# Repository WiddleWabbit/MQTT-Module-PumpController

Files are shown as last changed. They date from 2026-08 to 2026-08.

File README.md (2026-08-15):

# MQTT Module Pump Controller

*This Module is in testing and not fully tested.*

Module for the [MQTT Modular Controller Board](https://github.com/WiddleWabbit/MQTT-ModularControllerBoard). Controls and powers a single small 12 V pump.

## Features

- ATtiny1614 microcontroller
- I²C communication with motherboard (SDA/SCL)
- N-channel MOSFET + LM5060 high-side driver for pump control
- Overvoltage, undervoltage, and overcurrent protection
- Flyback diode, TVS, and filtering on pump output
- Green LED (pump running) and yellow LED (fault)
- 3-pin UPDI programming interface
- Adjustable passives for different pumps
- Maximum continuous pump current: 5 A

## Architecture

### Core Components

- **Microcontroller**: ATtiny1614
- **Pump Driver**: N-channel MOSFET paired with LM5060
- **Maximum Pump Current**: 5 A continuous
- **Programming**: 3-pin UPDI on PA0 (default fuse configuration: RSTPINCFG in FUSE.SYSCFG0 = 0x1)

### Protection (LM5060)

- **Overvoltage**: Triggers at 15.6 V (rising), releases at 13.7 V (falling)
- **Undervoltage**: Triggers at 9.3 V (falling), releases at 10.5 V (rising)
- **Overcurrent**: Fault threshold ~5.69 A
- **Timing**:
  - Startup threshold: ~157 ms
  - Transition threshold: ~72 ms
  - Overcurrent threshold: ~85 ms

### Output Protection

- Flyback diode across pump screw terminals
- TVS diode on output
- Filtering and smoothing capacitors
- 0 Ω resistor on output line (for testing / future provision)

### Pin Mapping (ATtiny1614)

| Function | Pin  |
|---|---|
| UPDI | PA0  |
| SDA (I²C) | PA1  |
| SCL (I²C) | PA2  |
| Pump warning LED | PA4  |
| Pump running LED | PA5  |
| Motherboard GPIO | PA6  |
| Motherboard SNS | PA7  |

### Communication

- I²C (SDA/SCL) to motherboard
- Motherboard sense (SNS) and general-purpose modular pin connected as listed above

### Indicators

- Green LED: Pump running
- Yellow LED: Fault condition

## Setup and Build

**Firmware**: Not yet implemented (TBA).

**Programming**:
- Use 3-pin UPDI interface on PA0
- Default fuse settings support UPDI (no change required)

**Hardware Notes**:
- Capacitors and resistors may be adjusted for different pumps
- Pump must not exceed 5 A continuous current on current configuration
- Conforms to the modular controller board 2x10 header interface

## Repository Contents

- KiCad schematic and PCB files
- Project configuration
- Backups folder
- Outputs folder

## License

This documentation is part of the MQTT-Module-PumpController project and is licensed under the CERN Open Hardware Licence Version 2 - Permissive (CERN-OHL-P-2.0).  
You may redistribute and modify this documentation under the terms of the CERN-OHL-P-2.0.  
This documentation is distributed WITHOUT ANY EXPRESS OR IMPLIED WARRANTY, INCLUDING OF MERCHANTABILITY, SATISFACTORY QUALITY AND FITNESS FOR A PARTICULAR PURPOSE. See the CERN-OHL-P-2.0 for applicable conditions.

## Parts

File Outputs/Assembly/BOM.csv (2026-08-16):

# | Qty | Reference | Value | Manufacturer | Manufacturer Part No | JLCPCB Part # | Package | Footprint
1 | 4 | C201,C205,C801,C805 | 0.1uF 10% 50V | YAGEO | CC0603KRX7R9BB104 | C14663 | 0603 | JLCPCB Basic:CAPC1608X90N
2 | 1 | C203 | 10uF 10% 50V | Samsung Electro-Mechanics | CL31A106KBHNNNE | C13585 | 1206 | JLCPCB Basic:CAPC3216X180N
3 | 1 | C802 | 22nF 10% 50V | Samsung Electro-Mechanics | CL10B223KB8NNNC | C21122 | 0603 | JLCPCB Basic:CAPC1608X90N
4 | 2 | C804,C806 | 22uF 20% 25V | Samsung Electro-Mechanics | CL21A226MAQNNNE | C45783 | 0805 | JLCPCB Basic:CAPC2012X75N
5 | 1 | C809 | 0.47uF 10% 50V | Samsung Electro-Mechanics | CL21B474KBFNNNE | C13967 | 0805 | JLCPCB Basic:CAPC2012X135N
6 | 1 | D201 | KT-0805Y | Hubei KENTO Elec | KT-0805Y | C2296 | 0805 | JLCPCB Basic:LED_0805_2012Metric
7 | 1 | D202 | KT-0805G | Hubei KENTO Elec | KT-0805G | C2297 | 0805 | JLCPCB Basic:LED_0805_2012Metric
8 | 1 | D303 | 13V 21.5V 1uA Leak | Littelfuse | SMBJ13CA | C224008 | DO-214AA | LITTELFUSE Diodes:DO-214AA_Bidirectional
9 | 1 | D602 | 5A 40V 500mV | onsemi | MBRS540T3G | C31849 | SMC(DO-214AB) | ONSEMI Diodes:DIOM7958X256N
10 | 1 | IC801 | LM5060MMX_NOPB | Texas Instruments | LM5060MMX/NOPB | C2676940 | VSSOP-10-0.5mm | TEXAS INSTRUMENTS ICs:SOP50P490X110-10N-LM5060
11 | 2 | J301,J302 | A2541WV-10P | CJT(Changjiang Connectors) | A2541WV-10P | C225485 | Plugin,P=2.54mm | CJT Connectors:PinHeader_1x10_P2.54mm_Vertical_Male
12 | 1 | J303 | 1715721 | Phoenix Contact | 1715721 | C480516 | Plugin,P=5.08mm | PHOENIX CONTACT Terminals:1715721
13 | 1 | J304 | A2541HWV-3P | CJT(Changjiang Connectors) | A2541HWV-3P | C225500 | Plugin,P=2.54mm | CJT Connectors:PinSocket_1x03_P2.54mm_Vertical_Female
14 | 1 | Q801 | 60V 38A | onsemi | NVD5C684NLT4G | C236252 | DPAK | ONSEMI Transistors:DPAK__SINGLE-GAUGE__TO-252_369C__ISSUE_F
15 | 2 | R201,R203 | 33Ω 1/8W 1% | UNI-ROYAL(Uniroyal Elec) | 0805W8F330JT5E | C17634 | 0805 | JLCPCB Basic:RESC2013X65N
16 | 2 | R202,R805 | 4.7kΩ 1/8W 1% | UNI-ROYAL(Uniroyal Elec) | 0805W8F4701T5E | C17673 | 0805 | JLCPCB Basic:RESC2013X65N
17 | 3 | R204,R801,R802 | 10kΩ 1/8W 1% | UNI-ROYAL(Uniroyal Elec) | 0805W8F1002T5E | C17414 | 0805 | JLCPCB Basic:RESC2013X65N
18 | 1 | R401 | 0Ω 1/8W 1% | UNI-ROYAL(Uniroyal Elec) | 0805W8F0000T5E | C17477 | 0805 | JLCPCB Basic:RESC2013X65N
19 | 1 | R803 | 56kΩ 1/4W 1% | YAGEO | RC1206FR-0756KL | C137251 | 1206 | YAGEO Resistors:RESC3116X65N
20 | 1 | R804 | 68kΩ 1/8W 1% | UNI-ROYAL(Uniroyal Elec) | 0805W8F6802T5E | C17801 | 0805 | JLCPCB Basic:RESC2013X65N
21 | 1 | R806 | 6.8kΩ 1/8W 1% | UNI-ROYAL(Uniroyal Elec) | 0805W8F6801T5E | C17772 | 0805 | JLCPCB Basic:RESC2013X65N
22 | 1 | S201 | Push Button SPST | XUNPU | TS-1088-AR02016 | C720477 | SMD,4x3mm | JLCPCB Basic:SW_TS-1088-AR02016
23 | 3 | TP202,TP401,U201 | ATtiny1614-SS,TestPoint |  |  |  |  | Package_SO:SOIC-14_3.9x8.7mm_P1.27mm,TestPoint:TestPoint_Pad_2.0x2.0mm

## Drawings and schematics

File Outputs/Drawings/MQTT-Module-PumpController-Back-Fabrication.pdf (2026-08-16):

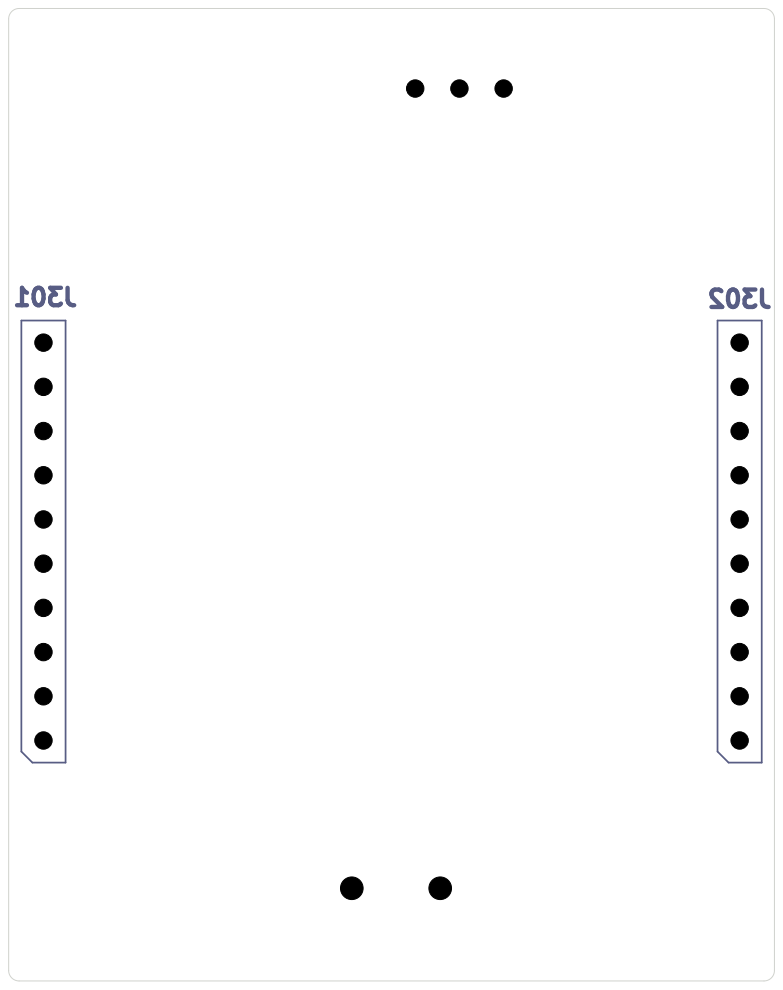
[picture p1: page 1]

Id: 1/1 Title: File: MQTT-Module-PumpController.kicad_pcb Sheet:

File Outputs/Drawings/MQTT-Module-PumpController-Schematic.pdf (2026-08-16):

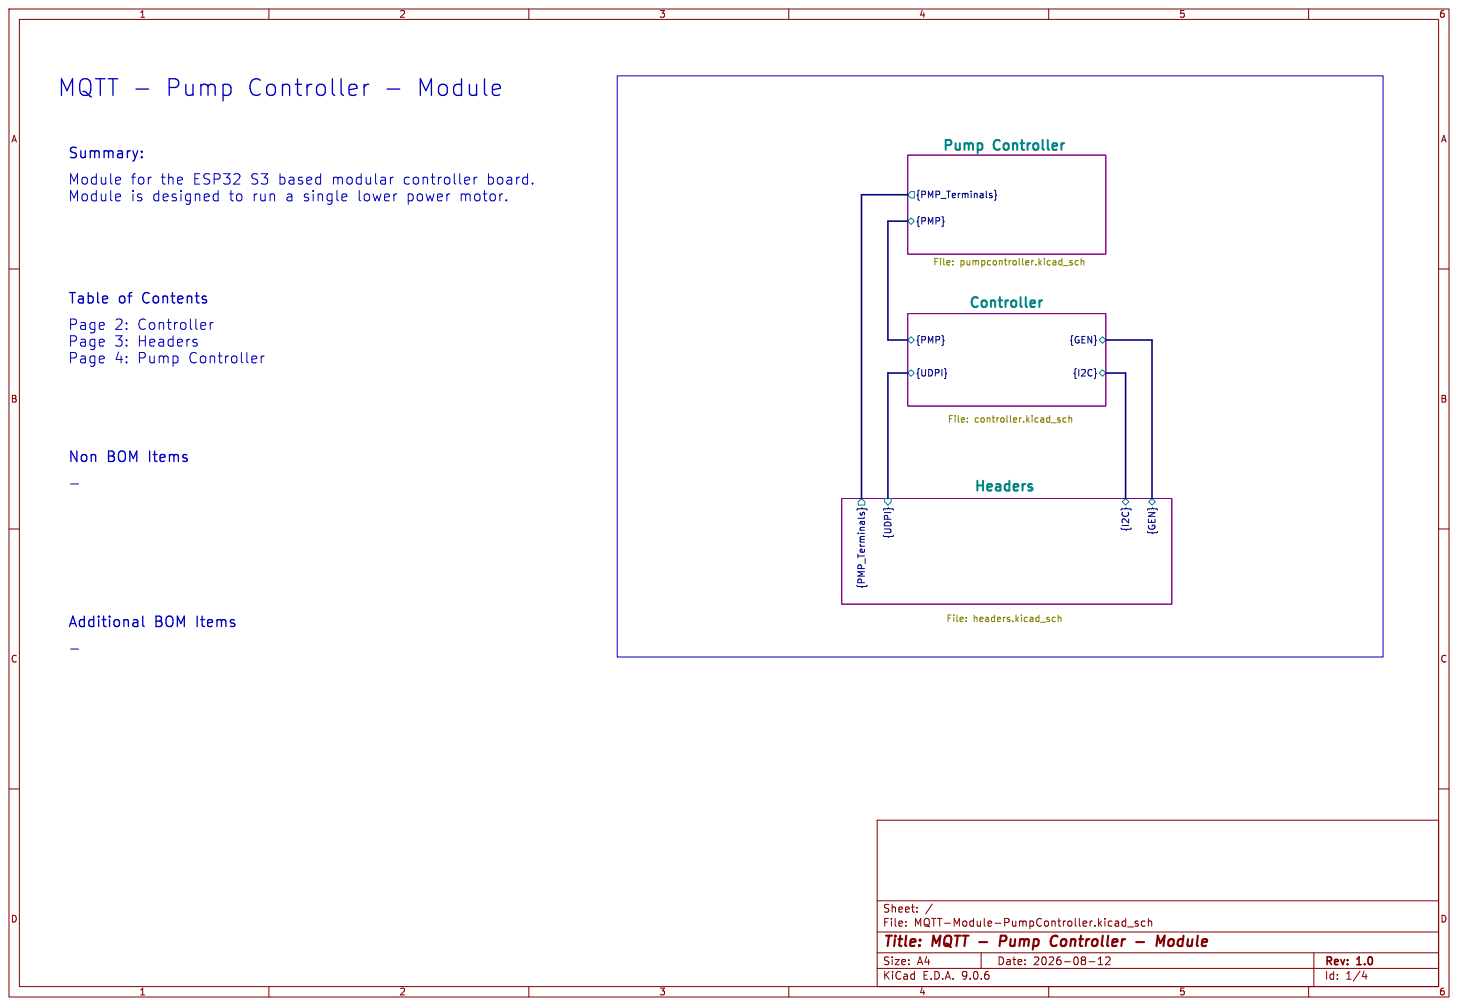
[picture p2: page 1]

Id: 1/4 Title: MQTT - Pump Controller - Module

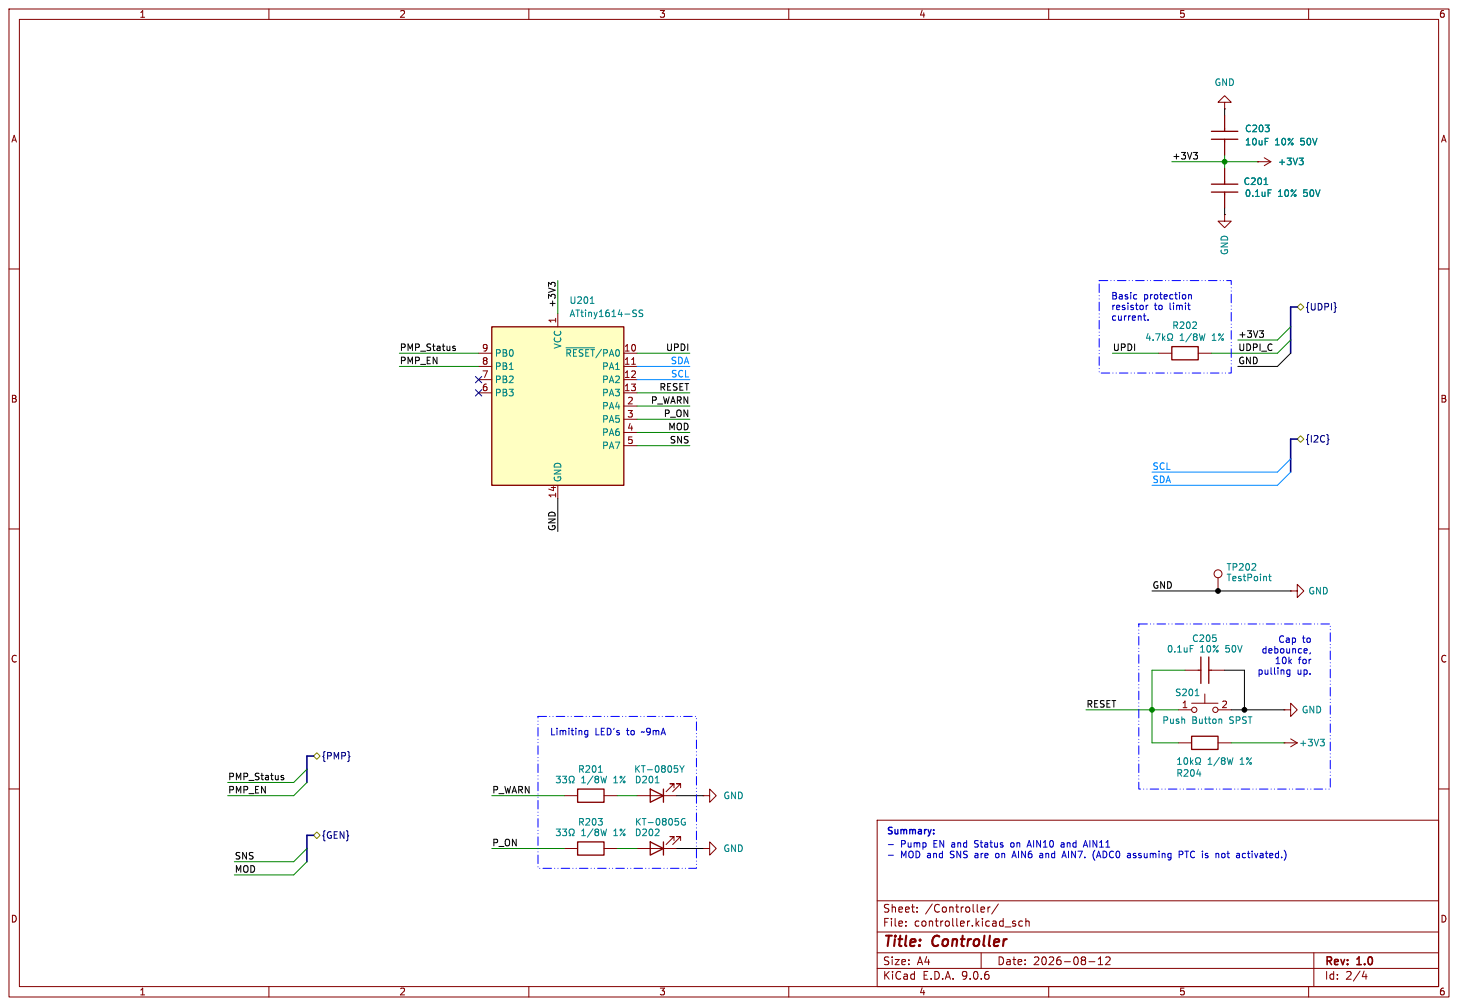
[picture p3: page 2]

Summary:
- Pump EN and Status on AIN10 and AIN11

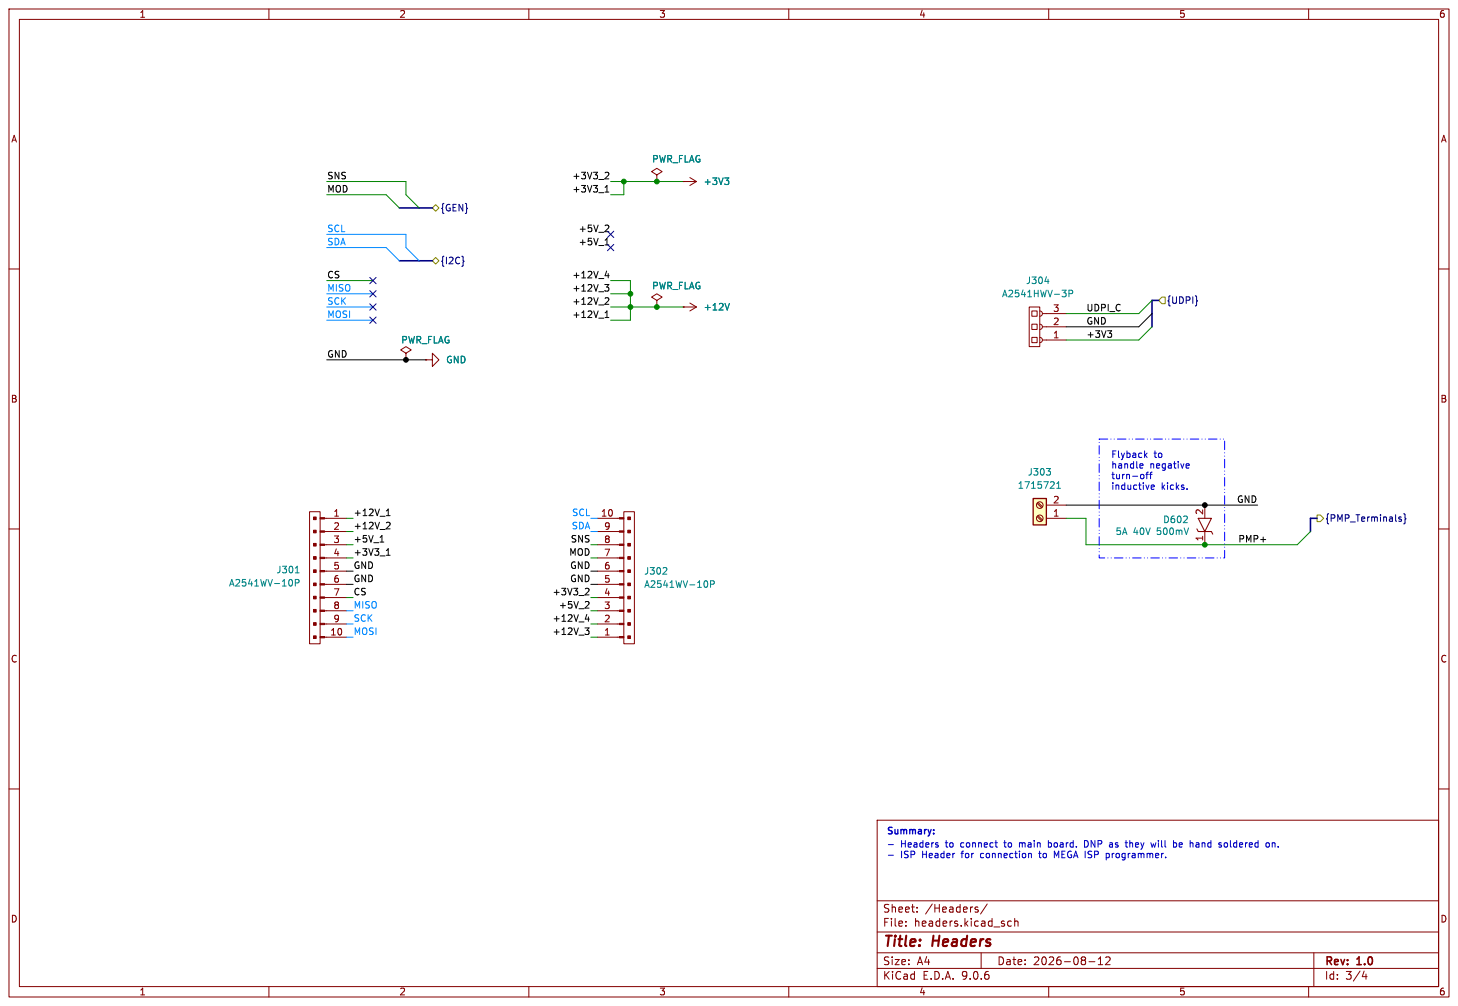
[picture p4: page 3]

File: headers.kicad_sch Sheet: /Headers/
Id: 3/4 Title: Headers

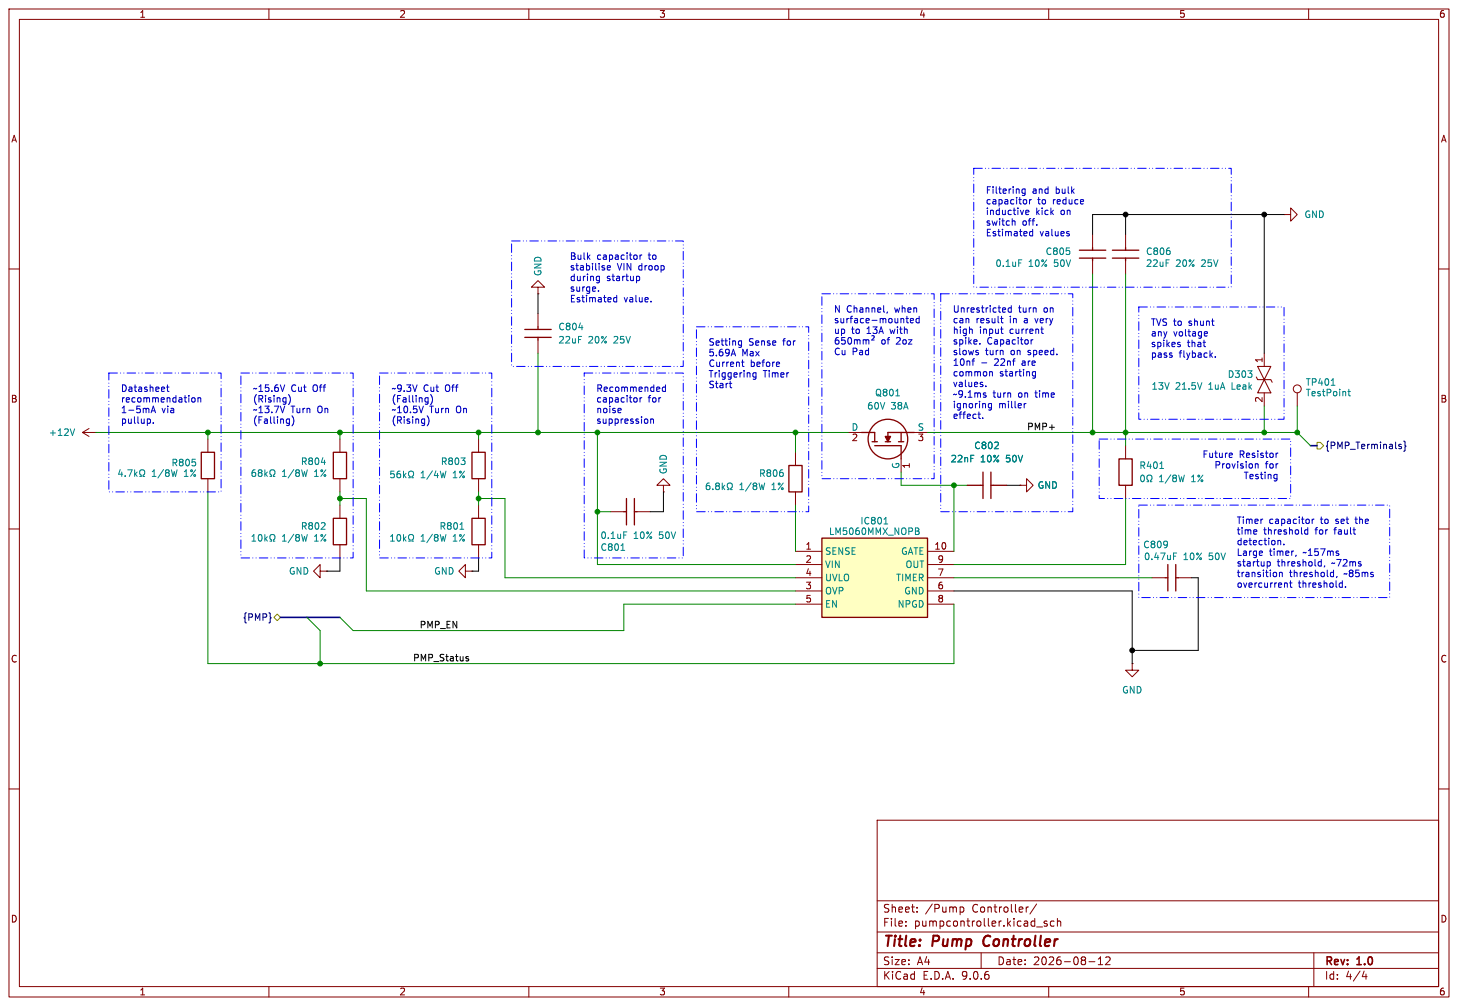
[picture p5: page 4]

can result in a very high input current spike. Capacitor slows turn on speed. 10nf - 22nf are

spikes that pass flyback. Recommended

common starting
values. ~9.1ms turn on time

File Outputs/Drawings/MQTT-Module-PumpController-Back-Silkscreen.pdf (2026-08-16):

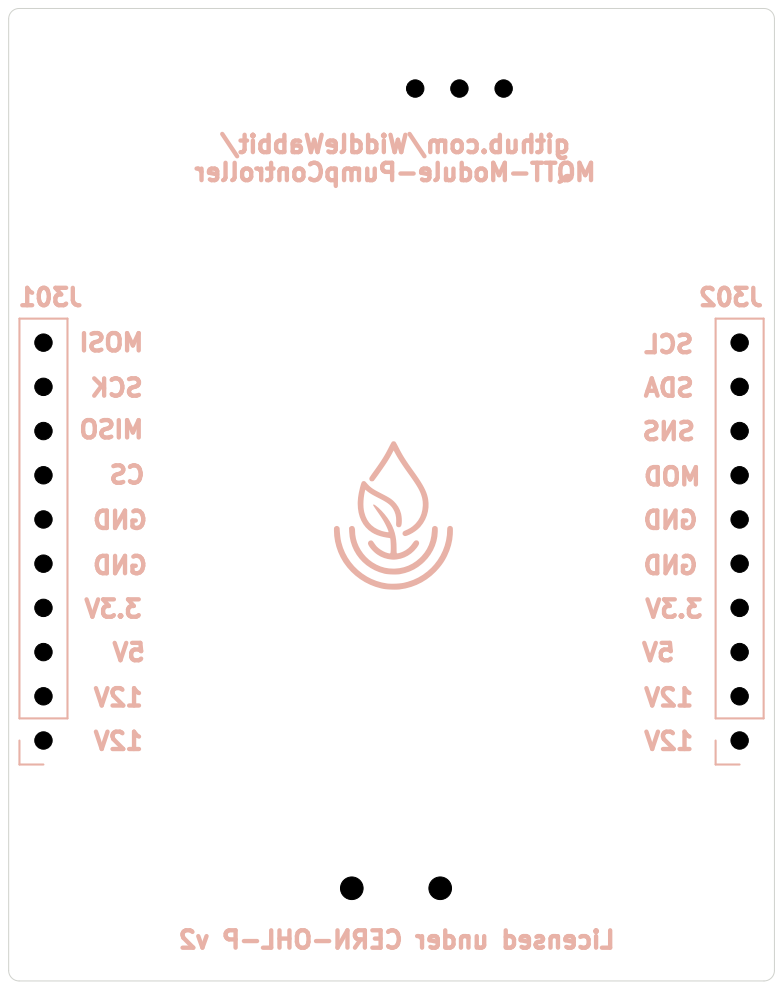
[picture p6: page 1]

Id: 1/1 Title: File: MQTT-Module-PumpController.kicad_pcb Sheet:

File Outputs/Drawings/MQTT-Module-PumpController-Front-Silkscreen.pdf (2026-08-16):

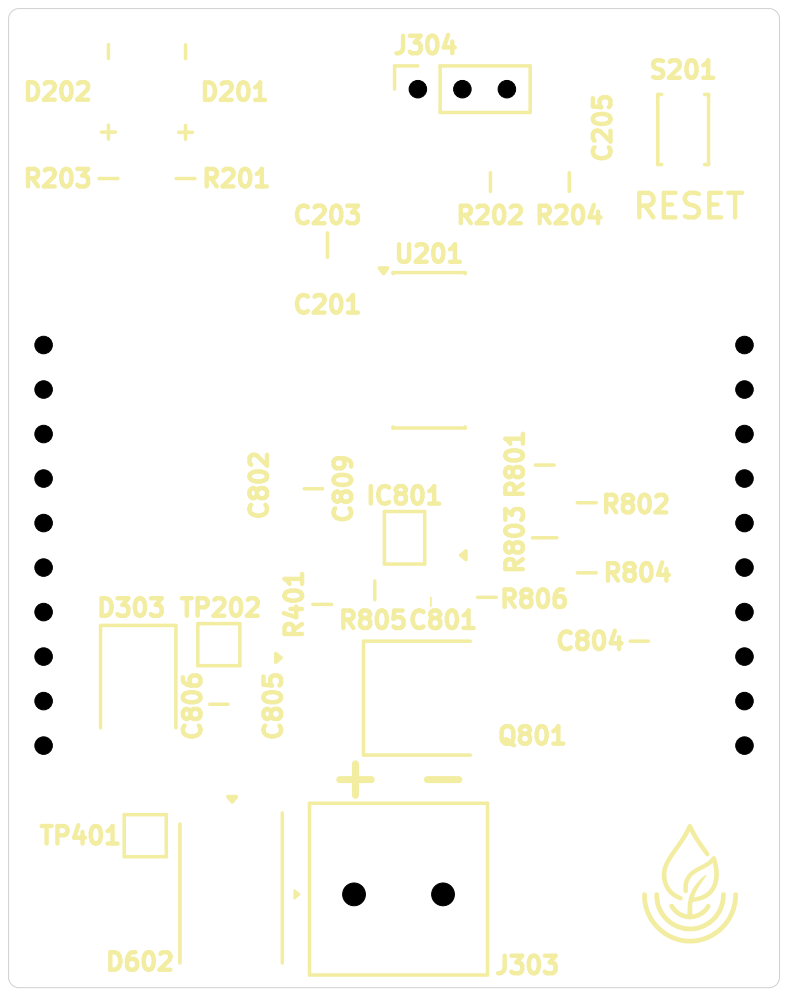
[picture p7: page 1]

Id: 1/1 Title: File: MQTT-Module-PumpController.kicad_pcb Sheet:

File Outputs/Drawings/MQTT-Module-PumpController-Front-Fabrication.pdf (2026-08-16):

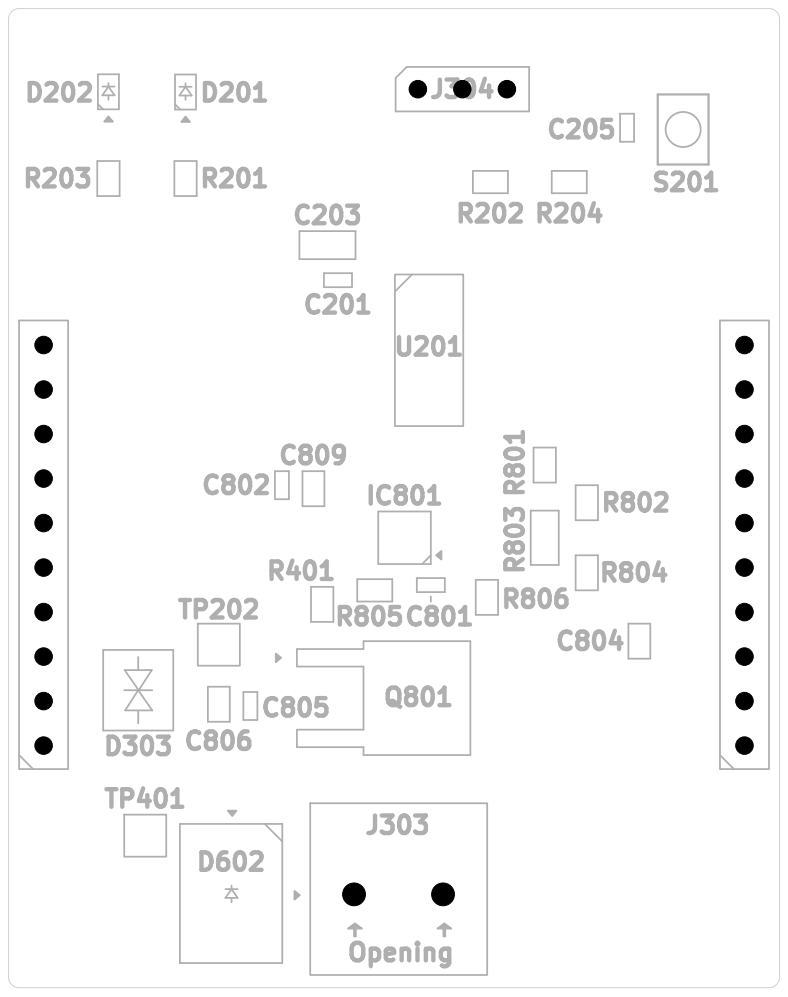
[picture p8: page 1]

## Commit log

2026-08-15 Initial Commit, module for running a small pump.
    [MQTT-Module-PumpController.kicad_pcb, MQTT-Module-PumpController.kicad_sch, controller.kicad_sch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]
2026-08-15 Updated silkscreen.
    [MQTT-Module-PumpController.kicad_pcb]
2026-08-16 Updated and completed base schematic and pcb. Added Reset Button.
    [MQTT-Module-PumpController.kicad_pcb, controller.kicad_sch]
2026-08-16 Finalised silkscreen. Generated outputs.
    [BOM.csv, JLCPCB_BOM.csv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]
2026-09-08 Updated BOM and regenerated.
2026-10-10 Added pin definitions.
2026-10-10 Simple LED flashing sketch to test and confirm the led's work.
2026-10-10 LED's power up during setup for 1 second
2026-10-21 Implemented pump commands in firmware. Adjusted schematic to use correct resistor values.
2026-10-22 Updated schematic and board with adjustments, updated board.
2026-10-25 Updated firmware to keep a timeout of no on command received. After 3 minutes automatically turn off the pump.
2026-10-31 Updated schematic, redesigned and included pump pressure switch. Regenerated all outputs.
2026-10-31 Swapped 12v pull up to 3.3v pull up and added 0.1uf cap to AND, then regenerated outputs.
2026-11-10 Updated to suit the new board. Included new commands for measuring voltage, current and reproting to the motherboard.
2026-11-10 Updated pump fault states.
